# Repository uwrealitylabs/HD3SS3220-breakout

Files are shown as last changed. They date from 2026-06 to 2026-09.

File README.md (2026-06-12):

# HD3SS3220 USB-C Mux Test Board

This is a project designed to bridge the gap between our FPGA board and modern USB-C devices, offering a great look into how the devices we interact with daily actually work under the hood! 

This test board utilizes the **HD3SS3220RNHR USB-C Multiplexer** to validate USB 3.0 functionality from our FPGA board's USB interface chip, effectively bridging a USB 3.0 Type-A (female) connection to a USB-C (female) connection. 

## 📸 Project Previews

**3D Render & PCB Layout:**
<br>
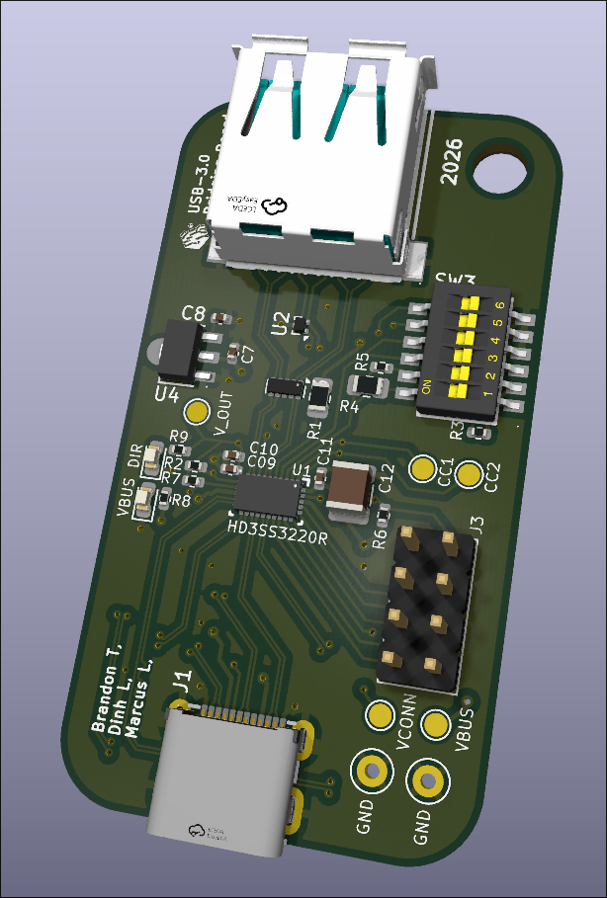
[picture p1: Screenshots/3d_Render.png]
3D Render

<br><br>
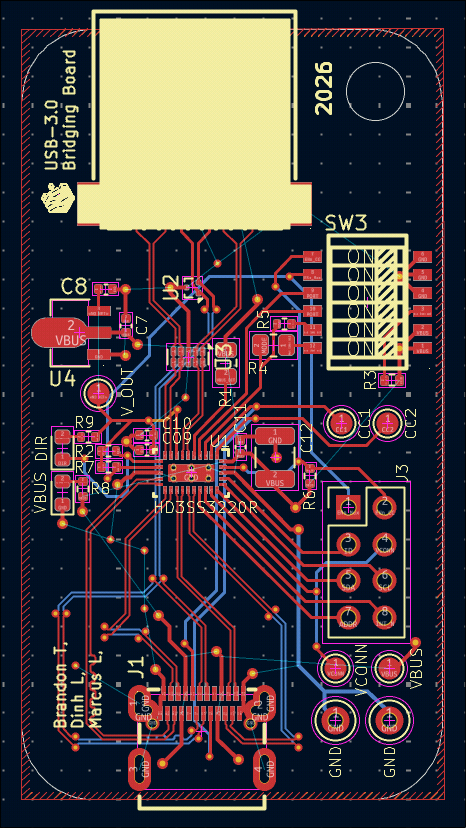
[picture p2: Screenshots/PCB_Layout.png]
PCB Layout

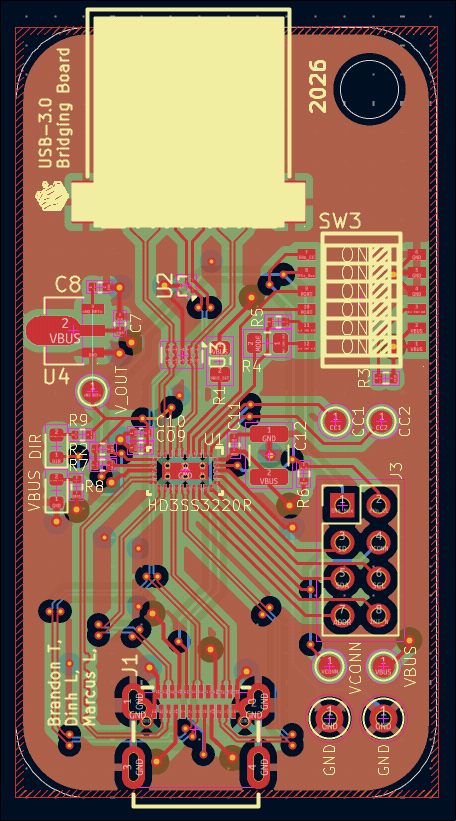
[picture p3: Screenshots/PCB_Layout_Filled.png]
PCB Layout


**Schematics:**
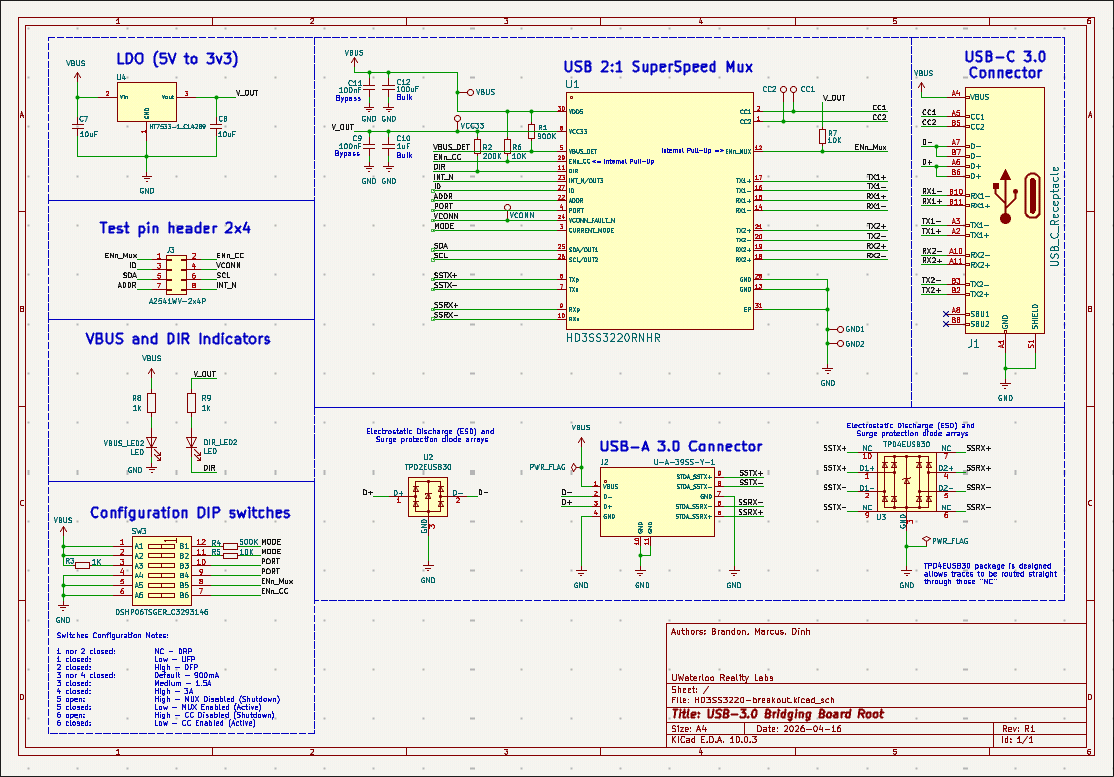
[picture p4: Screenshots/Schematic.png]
Schematic 1 - Overview

---

## ⚙️ Architecture & Configuration Notes
* **Configurable DRP, UFP and DFP Implementation:** Configured for Dual-Role Port, Downstream Facing Port and Upstream Facing Port functionality (refer to Section 4 of the HD3SS3220 datasheet).
* **Always-On Operation:** The chip automatically wakes up and cannot be disabled via a computer, as `ENn_CC` is tied directly to ground.
* **Power Constraints:** VBUS_DET and VDD5 are kept separate (though they default to 5V, power negotiation causes voltage variations). Currently, the board requires an **external 5V power source**.

---

## 📏 High-Speed Routing Constraints (USB 3.0)

To ensure 5 Gbps signal integrity, the following rigid design rules were implemented during layout:

### 1. Differential Pair Routing & Symmetry
* **Intrapair Matching:** Length matching is strictly intrapair (TX+ to TX-, RX+ to RX-). TX and RX pairs do not need to match each other. Serpentine routing is applied as close to the mismatched ends as possible.
* **Symmetry:** High-speed pairs are purely symmetrical. Any IC breakout mismatch is resolved within 0.25 inches of the package.
* **Via Management:** Vias are minimized. Any unavoidable layer transitions ensure via stubs are kept under **15 mils** (back-drilled if necessary).

### 2. Clearances & Spacing
* **5W Rule:** Maintained a spacing of at least 5x the trace width between different high-speed signal pairs.
* **Keep-Outs:** Maintained >30 mils clearance from normal signals, and >50 mils from clocks/oscillators (not that we have one).
* **Plane Edges:** Traces are routed at least 90 mils away from the edge of the GND reference plane, and at least 1.5W away from any generic plane voids.

### 3. ESD Protection & Signal Path
* **ESD Placement:** TPD2EUSB30 / TPD4EUSB30 diodes are placed immediately at the USB connector.
* **Geometry:** Flow-through routing only (no stubs). Sharp bends are eliminated using large-radii rounded corners to prevent E-field buildup.
* **Test Points:** Strictly **NO** test points on high-speed pairs.

### 4. AC Coupling Capacitors
* **Footprints:** Symmetrically placed **0402** packages.

---

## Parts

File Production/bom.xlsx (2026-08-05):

 |  |  |  | HD3SS3220 Breakout Board Bill of Materials
 |  |  |  | Revision: 0
 |  |  |  | 2026-06-15
ITEM | REFERENCE | PACKAGE | QTY | DESCRIPTION | LCSC PART # | MPN | MANUFACTURER
1 | C1, C2 | 0402 | 2 | Capacitor 10uF X5R 10V | C7472949 | HGC0402R5106M100NTEJ | Chinocera
2 | C3, C4 | 0402 | 2 | Capacitor 100nF X5R 16V | C106204 | CC0402KRX5R7BB104 | YAGEO
3 | C5 | 1210 | 1 | Capacitor 100uF X5R 16V | C394395 | EMK325ABJ107MM-T | Taiyo Yuden
4 | C6 | 0402 | 1 | Capacitor 1uF X5R 16V | C2177690 | EMK105BJ105MV-F | Taiyo Yuden
5 | DIR, VBUS_2 | 0603 | 2 | LED Dome Lens SMD | C375576 | E6Q0603VGAC1UDA | EKINGLUX
6 | J1 | SMD | 1 | Connector USB 3.1 Type-C 24P | C920230 | TYPEC-324G-BCP24 | XUNPU
7 | J2 | SMD | 1 | Connector USB 3.0 Type-A 9P | C530639 | U-A-39SS-Y-1 | Korean Hroparts Elec
8 | J3 | THT | 1 | Connector Header 8P | C225519 | A2541WV-2x4P | Changjiang Connectors
9 | R1 | 0805 | 1 | Resistor 900kΩ ±1% 125mW | C52209984 | CL0805FN900KPS | CHANGLONG
10 | R2 | 0402 | 1 | Resistor 200kΩ ±1% 0.1W | C413111 | ERJ2RKF2003X | PANASONIC
11 | R3, R8, R9 | 0402 | 3 | Resistor 1kΩ ±1% 0.1W | C242161 | ERJ2RKF1001X | PANASONIC
12 | R4 | 0805 | 1 | Resistor 500kΩ ±0.1% 125mW | C316218 | AR05BTCW5003 | Viking
13 | R5, R6, R7 | 0402 | 1 | Resistor 10kΩ ±1% 100mW | C4326584 | ERJ-H2RF1002X | PANASONIC
14 | SW1 | SMD | 1 | Switch DIP SPST 25mA 24V | C3293146 | DSHP06TSGER | kangshen
15 | U1 |  | 1 | USB Type-C DRP Port Controller with SS 2:1 MUX | C165155 | HD3SS3220RNHR | Texas Instruments
16 | U2, U3, U4 | USON-10 | 3 | ESD DIODE 5.5VWM 8VC | C90627 | TPD4EUSB30DQAR | Texas Instruments
17 | U4 | SOT-89-3 | 1 | IC Reg Linear 3.3V 100mA | C14289 | HT7533-1 | HOLTEK

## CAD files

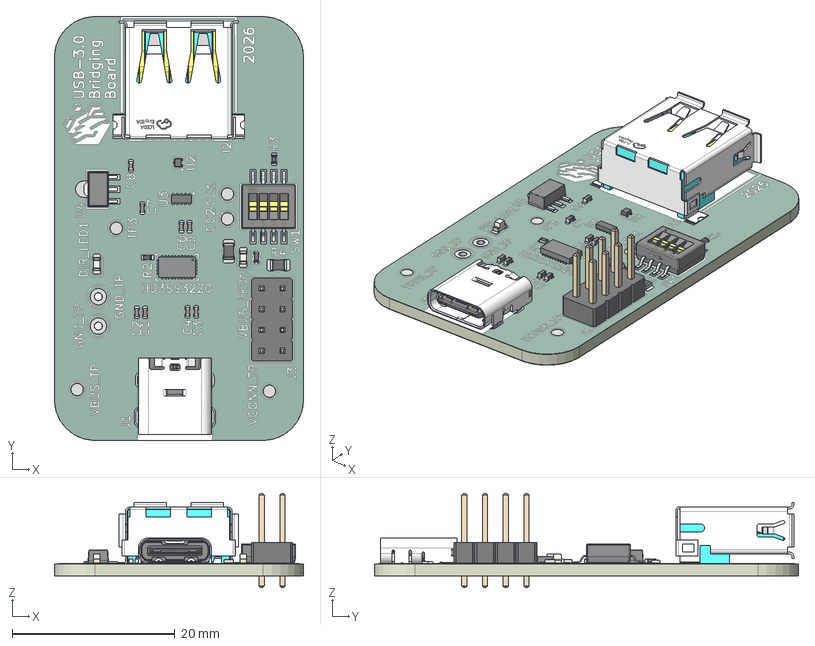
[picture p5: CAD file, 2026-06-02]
HD3SS320_Board.step
30.6 x 52.0 x 11.5 mm
USON_10_25x10mm_Pitch05mm
SW-SMD_8P-L6.7-W5.4-H2.3-LS8.4-P1.27
LED_0603_1608Metric x 2
PinHeader_2x04_P254mm_Vertical
C_0402_1005Metric x 8
DRT_3
USB-3.0-A_U-A-39SS-Y-1
R_0805_2012Metric x 2
R_0402_1005Metric x 3
SOT-89-3_L4.3-W2.5-H1.6-LS4.1-P1.50
CUI_DEVICES_UJ31-CH-3-SMT-TR
HD3SS3220IRNHT
HD3SS3220-breakout_copper
HD3SS3220-breakout_pad
HD3SS3220-breakout_via
HD3SS3220-breakout_silkscreen
HD3SS3220-breakout_soldermask x 2
HD3SS3220-breakout_PCB

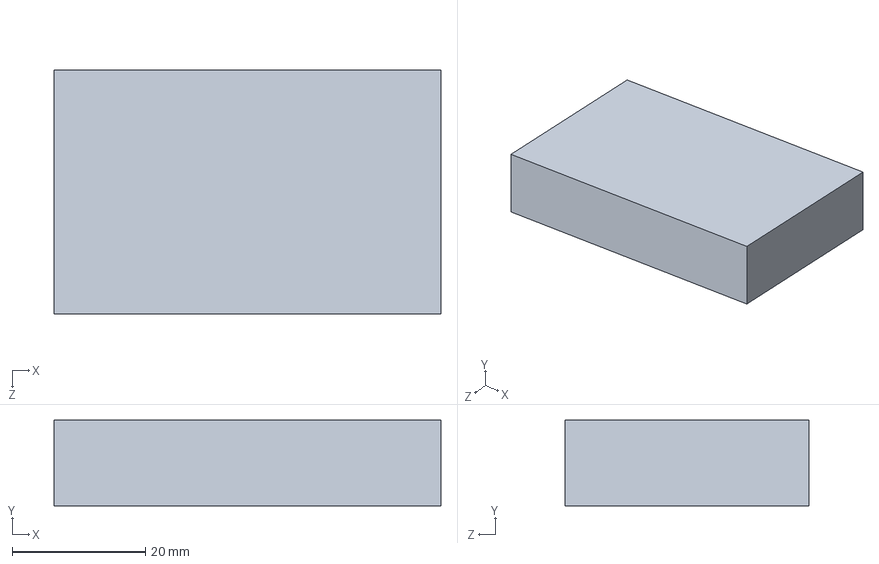
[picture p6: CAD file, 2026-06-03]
Printed Case/USB_Case.SLDPRT
58.0 x 12.9 x 36.6 mm

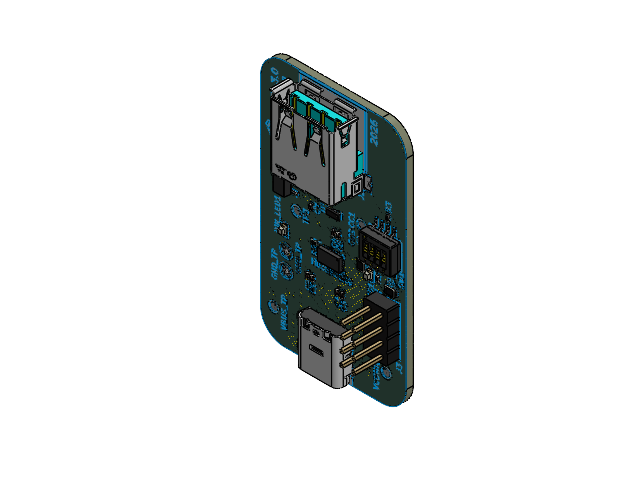
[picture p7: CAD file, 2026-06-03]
Printed Case/HD3SS320_Board.SLDASM
USON_10_25x10mm_Pitch05mm.step
SW-SMD_8P-L6.7-W5.4-H2.3-LS8.4-P1.27-0.step
LED_0603_1608Metric-1.step x 2
PinHeader_2x04_P254mm_Vertical.step
C_0402_1005Metric-2.step x 8
DRT_3.step
USB-3.0-A_U-A-39SS-Y-1-3.step
R_0805_2012Metric-4.step x 2
R_0402_1005Metric-5.step x 3
SOT-89-3_L4.3-W2.5-H1.6-LS4.1-P1.50-6.step
CUI_DEVICES_UJ31-CH-3-SMT-TR.step
HD3SS3220IRNHT.step
HD3SS3220-breakout_copper.step
HD3SS3220-breakout_pad.step
HD3SS3220-breakout_via.step
HD3SS3220-breakout_silkscreen.step
HD3SS3220-breakout_soldermask.step
HD3SS3220-breakout_soldermask-7.step
HD3SS3220-breakout_PCB.step

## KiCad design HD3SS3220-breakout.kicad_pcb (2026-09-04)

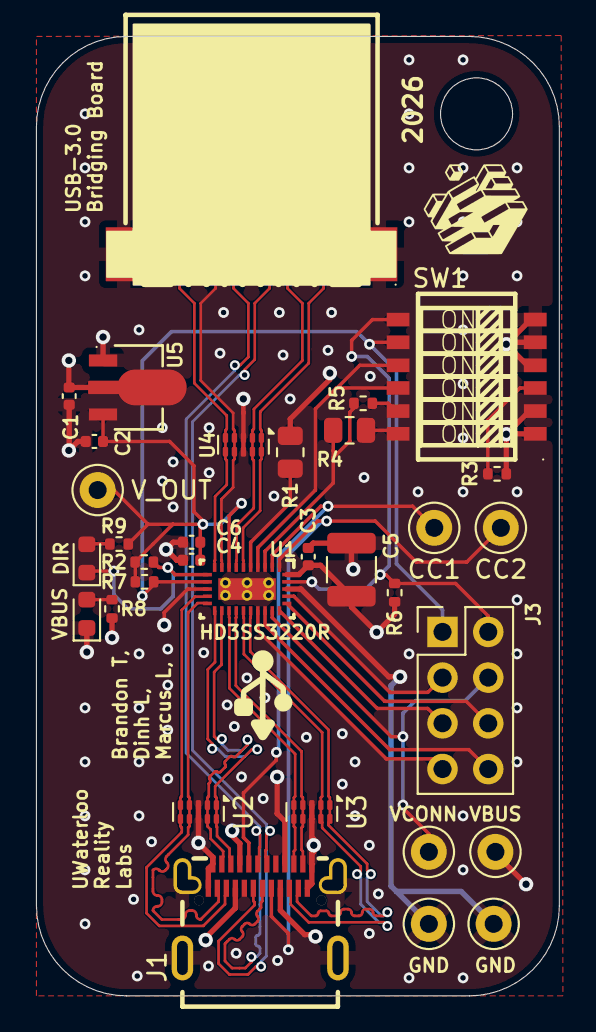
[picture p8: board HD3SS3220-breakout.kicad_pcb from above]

Board: 4 copper layers, 29.0 x 53.3 mm, 33 parts (0 on the bottom side), 36 nets.

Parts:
C1, C2: 10uF; C_0402_1005Metric
C3, C4: 100nF; C_0402_1005Metric
C5: 100uF; C_1210_3225Metric
C6: 1uF; C_0402_1005Metric
CC1: CC1; TestPoint_Keystone_5000-5004_Miniature
CC2: CC2; TestPoint_Keystone_5000-5004_Miniature
DIR: LED; LED_0603_1608Metric
GND: GND2; TestPoint_Keystone_5000-5004_Miniature
GND#2: GND1; TestPoint_Keystone_5000-5004_Miniature
J1: USB_C_Receptacle; USB-C-SMD_TYPEC-324G-BCP24
J2: U-A-39SS-Y-1; USB-3.0-A_U-A-39SS-Y-1
J3: A2541WV-2x4P; PinHeader_2x04_P2.54mm_Vertical
R1: 900K; R_0805_2012Metric
R2: 200K; R_0402_1005Metric
R3: 1K; R_0402_1005Metric
R4: 500K; R_0805_2012Metric
R5, R6, R7: 10K; R_0402_1005Metric
R8, R9: 1k; R_0402_1005Metric
SW1: DSHP06TSGER_C3293146; SW-SMD_12P-L9.2-W5.4-P1.27-LS8.5
U1: HD3SS3220RNHR; HD3SS3220IRNHR
U2, U3, U4: TPD4EUSB30; USON-10_2.5x1.0mm_P0.5mm
U5: HT7533-1_C14289; SOT-89-3_L4.5-W2.5-P1.50-LS4.2-BR
VBUS: LED; LED_0603_1608Metric
VBUS#2: VBUS; TestPoint_Keystone_5000-5004_Miniature
VCONN: VCONN; TestPoint_Keystone_5000-5004_Miniature
V_OUT: VCC33; TestPoint_Keystone_5000-5004_Miniature

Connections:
/ADDR: J3.7, U1.22 (ADDR)
/CC1: CC1.1 (1_1), J1.A5 (CC1), U1.2 (CC1)
/CC2: CC2.1 (1_1), J1.B5 (CC2), U1.1 (CC2)
/D+: J1.A6 (DP1), J1.B6 (DP2), J2.3 (D+)
/D-: J1.A7 (DN1), J1.B7 (DN2), J2.2 (D-)
/DIR: DIR.1 (K), R2.2, U1.11 (DIR)
/ENn_CC: J3.2, R6.2, SW1.7 (B6), U1.29 (ENn_CC)
/ENn_Mux: J3.1, R7.2, SW1.8 (B5), U1.12 (ENn_MUX)
/ID: J3.3, U1.27 (ID)
/INT_N: J3.8, U1.23 (INT_N/OUT3)
/MODE: R4.2, R5.2, U1.3 (CURRENT_MODE)
/PORT: SW1.9 (B4), SW1.10 (B3), U1.4 (PORT)
/RX1+: J1.B11 (SSRXp1), U1.15 (RX1+), U2.4 (D2+), U2.7 (NC)
/RX1-: J1.B10 (SSRXn1), U1.14 (RX1-), U2.5 (D2-), U2.6 (NC)
/RX2+: J1.A11 (SSRXp2), U1.19 (RX2+), U3.4 (D2+), U3.7 (NC)
/RX2-: J1.A10 (SSRXn2), U1.18 (RX2+), U3.5 (D2-), U3.6 (NC)
/SCL: J3.6, U1.26 (SCL/OUT2)
/SDA: J3.5, U1.25 (SDA/OUT1)
/SSRX+: J2.6 (STDA_SSRX+), U1.9 (RXp), U4.4 (D2+), U4.7 (NC)
/SSRX-: J2.5 (STDA_SSRX-), U1.10 (RXn), U4.5 (D2-), U4.6 (NC)
/SSTX+: J2.9 (STDA_SSTX+), U1.6 (TXp), U4.1 (D1+), U4.10 (NC)
/SSTX-: J2.8 (STDA_SSTX-), U1.7 (TXn), U4.2 (D1-), U4.9 (NC)
/TX1+: J1.A2 (SSTXP1), U1.17 (TX1+), U2.2 (D1-), U2.9 (NC)
/TX1-: J1.A3 (SSTXn1), U1.16 (TX1-), U2.1 (D1+), U2.10 (NC)
/TX2+: J1.B2 (SSTXp2), U1.21 (TX2+), U3.1 (D1+), U3.10 (NC)
/TX2-: J1.B3 (SSTXn2), U1.20 (TX2-), U3.2 (D1-), U3.9 (NC)
/VBUS_DET: R1.2, U1.5 (VBUS_DET)
/VCONN: J3.4, U1.24 (VCONN_FAULT_N), VCONN.1 (1_1)
GND: C1.2, C2.2, C3.1, C4.1, C5.1, C6.1, GND.1 (1_1), GND#2.1 (1_1), J1.1 (EP), J1.2 (EP), J1.3 (EP), J1.4 (EP), J1.A1 (GND), J1.A12 (GND), J1.B1 (GND), J1.B12 (GND), J2.4 (GND), J2.7 (GND), J2.10 (GND), J2.11 (GND), SW1.4 (A4), SW1.5 (A5), SW1.6 (A6), U1.13 (GND), U1.28 (GND), U1.31 (EP), U2.3 (GND), U2.8 (GND), U3.3 (GND), U3.8 (GND), U4.3 (GND), U4.8 (GND), U5.1 (GND), VBUS.1 (K)
unnamed: DIR.2 (A), R9.2
unnamed: R3.2, SW1.3 (A3)
unnamed: R4.1, SW1.12 (B1)
unnamed: R5.1, SW1.11 (B2)
unnamed: R8.2, VBUS.2 (A)
VBUS: C1.1, C3.2, C5.2, J1.A4 (VBUS), J1.A9 (VBUS), J1.B4 (VBUS), J1.B9 (VBUS), J2.1 (VBUS), R1.1, R3.1, R6.1, R8.1, SW1.1 (A1), SW1.2 (A2), U1.30 (VDD5), U5.2 (Vin), VBUS#2.1 (1_1)
V_OUT: C2.1, C4.2, C6.2, R2.1, R7.1, R9.1, U1.8 (VCC33), U5.3 (Vout), V_OUT.1 (1_1)

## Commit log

2026-02-20 First draft schematic + notes
    [HD3SS3220-breakout.kicad_pcb, HD3SS3220-breakout.kicad_sch]
2026-02-23 Reorganize library to follow KiCad naming conventions
    Restructure the library into categorized directories following KiCad's
    official library naming scheme. Symbols use .kicad_symdir directories,
    footprints use .pretty directories, and 3D models use .3dshapes
    directories, all grouped by component category (MCU_RaspberryPi,
    MCU_WCH, Interface_USB, Sensor_Motion, Regulator_Linear, Memory_Flash,
    Connector_USB, Connector, Device, Switch).
    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
    [HD3SS3220-breakout.kicad_sch]
2026-02-23 Net labels
    [HD3SS3220-breakout.kicad_sch]
2026-02-24 further reorganizaing
    [HD3SS3220-breakout.kicad_sch]
2026-02-26 switches and ldo
    [HD3SS3220-breakout.kicad_sch]
2026-02-28 power glag
2026-02-28 post review on 02/27/2026
    [HD3SS3220-breakout.kicad_sch]
2026-02-28 usb-a 3.0 connector
    [HD3SS3220-breakout.kicad_pcb, HD3SS3220-breakout.kicad_sch]
2026-02-28 all reorged
    [HD3SS3220-breakout.kicad_sch]
2026-03-06 more stuff
    [HD3SS3220-breakout.kicad_sch]
2026-03-11 new files
    [HD3SS3220-breakout.kicad_sch]
2026-03-13 trace info
2026-03-16 new pcb stuff
    [HD3SS3220-breakout.kicad_pcb, HD3SS3220-breakout.kicad_sch]
2026-03-26 Added indicator LED's and test points
    [HD3SS3220-breakout.kicad_sch]
2026-03-29 pain and suffering
    [HD3SS3220-breakout.kicad_pcb, HD3SS3220-breakout.kicad_sch]
2026-03-29 Fixed footprint pad naming issues
    [HD3SS3220-breakout.kicad_pcb, HD3SS3220-breakout.kicad_sch]
2026-03-31 Added dip switch footprint to library and PCB editor
    [HD3SS3220-breakout.kicad_pcb, HD3SS3220-breakout.kicad_sch]
2026-04-03 added more footprints
    [HD3SS3220-breakout.kicad_pcb, HD3SS3220-breakout.kicad_sch]
2026-04-04 Fixed mux footprint somewhat, starting to route
    [HD3SS3220-breakout.kicad_pcb, HD3SS3220-breakout.kicad_sch]
2026-04-27 cursed vias
    [HD3SS3220-breakout.kicad_pcb]
2026-05-29 Schematic Hierarchy Implementation
2026-05-30 Hierarchy Schematic Implementation and Clean-up (Please Refer to this Version for previous sym-lib-table)
    [HD3SS3220-breakout.kicad_sch, configuration_debug.kicad_sch, high_speed_components.kicad_sch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]
2026-05-31 Routing Complete (DRC Checker Errors needs fixing)
    [HD3SS3220-breakout.kicad_pcb, configuration_debug.kicad_sch, high_speed_components.kicad_sch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]
2026-06-01 DRC Errors Fixed, BOM Cleaned up and Generated, Gerber Generated
    [HD3SS3220-breakout.kicad_pcb, HD3SS3220-breakout.kicad_sch, configuration_debug.kicad_sch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]
2026-06-02 Hopefully final DRC error fixed by reducing Minimum Spoke Count from 2 to 1
    [HD3SS320_Board.step, HD3SS3220-breakout.kicad_pcb]
2026-06-02 Add Screenshots for README
    [HD3SS3220-breakout.kicad_pcb]
2026-06-02 Add README for HD3SS3220 USB-C Mux Test Board
2026-06-02 Revise schematic images and descriptions in README
    Updated schematic images in README with new descriptions.
2026-06-02 Remove plane voiding information from README
    Removed plane voiding details for AC coupling capacitors.
2026-06-03 Protruding USB connectors for easier CAD design
    [HD3SS320_Board.SLDASM, HD3SS3220-breakout.kicad_pcb, USB_Case.SLDPRT]
2026-06-04 Holes drilled for easier case CAD design
    [HD3SS3220-breakout.kicad_pcb]
2026-06-07 Added missing components (Coupling capacitors and led resistors, wired board again
    [HD3SS3220-breakout.kicad_pcb, HD3SS3220-breakout.kicad_sch, configuration_debug.kicad_sch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]
2026-06-10 Schematic Review: Removed Coupling Capacitors (no USB controller just mux)
    [HD3SS3220-breakout.kicad_pcb, HD3SS3220-breakout.kicad_sch]
2026-06-12 Rerouted for new elements added (5 DRC errors left)
    [HD3SS3220-breakout.kicad_pcb, HD3SS3220-breakout.kicad_sch]
2026-06-12 Revise schematics and add filled PCB layout image
    Updated schematics section in README and added filled PCB layout image.
2026-06-12 Add filled PCB layout image to README
2026-06-14 Rerouting PCB after fixes on schematic, fixed subsequent DRC errors
    [HD3SS3220-breakout.kicad_pcb]
2026-06-15 Generated Gerber files and proper BOM
    [HD3SS3220-breakout.kicad_pcb, HD3SS3220-breakout.kicad_sch, bom.xlsx]
2026-06-28 Corrected ESD Diodes logic
    [HD3SS3220-breakout.kicad_pcb, HD3SS3220-breakout.kicad_sch]
2026-07-09 Via to Ground Pour Clearance Fixed, D+/D- Lines Split Shortened, Ground Stitching Added, Other Symbols and Footprint Changed
    [HD3SS3220-breakout.kicad_pcb, HD3SS3220-breakout.kicad_sch]
2026-07-09 Added suggested D+/D- routing
    [HD3SS3220-breakout.kicad_pcb]
2026-07-09 Added fabrication notes and cleaned up board
    [HD3SS3220-breakout.kicad_pcb]
2026-07-19 Board Stackup Updated to match JLCPCB 3313 Stackup and Differential Pair Constraints updated with calculated values
    [HD3SS3220-breakout.kicad_pcb]
2026-07-20 Rerouted using the new design constraints... DRC errors left are with the USB-C footprint
    [HD3SS3220-breakout.kicad_pcb]
2026-07-24 Tuned differential pair lengths and edited the manufacturing notes
    [HD3SS3220-breakout.kicad_pcb]
2026-08-05 Gerber Files generated for Manufacturing
    [HD3SS3220-breakout-B_Courtyard.gbr, HD3SS3220-breakout-B_Cu (Signal).gbl, HD3SS3220-breakout-B_Fab.gbr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]
2026-08-05 Footprint and symbol fix
    [HD3SS3220-breakout.kicad_pcb, HD3SS3220-breakout.kicad_sch]
2026-09-04 Gerber files generated
    [HD3SS3220-breakout-B_Courtyard.gbr, HD3SS3220-breakout-B_Cu (Signal).gbl, HD3SS3220-breakout-B_Fab.gbr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]
